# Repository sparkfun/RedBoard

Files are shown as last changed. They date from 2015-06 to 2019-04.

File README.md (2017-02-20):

SparkFun RedBoard
============================

[SparkFun RedBoard  
*SparkFun RedBoard (DEV-13975)*](https://www.sparkfun.com/products/13975)

The RedBoard combines the simplicity of the UNO's Optiboot bootloader (which is used in the Pro series), the stability of the FTDI (which we all missed after the Duemilanove was discontinued) and the R3 shield compatibility of the latest Arduino UNO R3.

The RedBoard can be programmed over a USB Mini-B cable using the Arduino IDE: Just plug in the board, select "Arduino UNO" from the board menu and you're ready to upload code.

Repository Contents
-------------------
* **/Documentation** - Data sheets, additional product information
* **/Hardware** - Eagle design files (.brd, .sch)
* **/Production** - Production panel files (.brd)

Documentation
--------------
* **[Hookup Guide](https://learn.sparkfun.com/tutorials/redboard-hookup-guide)** - Basic hookup guide for the Redboard.
* **[SparkFun Fritzing repo](https://github.com/sparkfun/Fritzing_Parts)** - Fritzing diagrams for SparkFun products.
* **[SparkFun 3D Model repo](https://github.com/sparkfun/3D_Models)** - 3D models of SparkFun products. 

License Information
-------------------

This product is _**open source**_! 

Please review the LICENSE.md file for license information. 

If you have any questions or concerns on licensing, please contact techsupport@sparkfun.com.

Distributed as-is; no warranty is given.

- Your friends at SparkFun.

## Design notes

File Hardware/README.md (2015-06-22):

SparkFun Redboard Design Files
=====================================

The .sch and .brd files hare are Eagle CAD schematic and PCB design files from SparkFun Electronics.
A freeware version of Eagle can be found [here](http://www.cadsoftusa.com/download-eagle/freeware/).

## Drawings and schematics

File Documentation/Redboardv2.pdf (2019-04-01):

# RedBoard (DEV-13975)

## Programmed with Arduino (Uno)

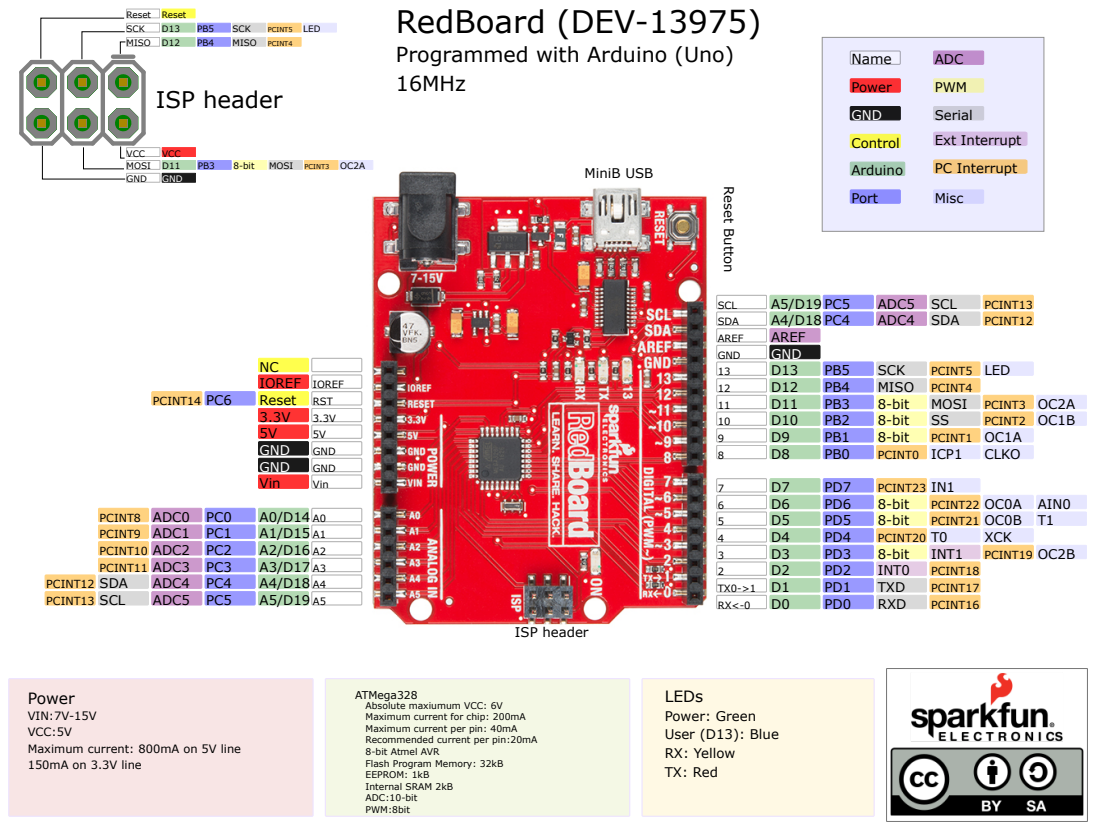
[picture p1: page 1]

ATMega328
Absolute maxiumum VCC: 6V
Maximum current for chip: 200mA
Maximum current per pin: 40mA
Recommended current per pin:20mA
8-bit Atmel AVR
Flash Program Memory: 32kB
EEPROM: 1kB
Internal SRAM 2kB
ADC:10-bit
PWM:8bit

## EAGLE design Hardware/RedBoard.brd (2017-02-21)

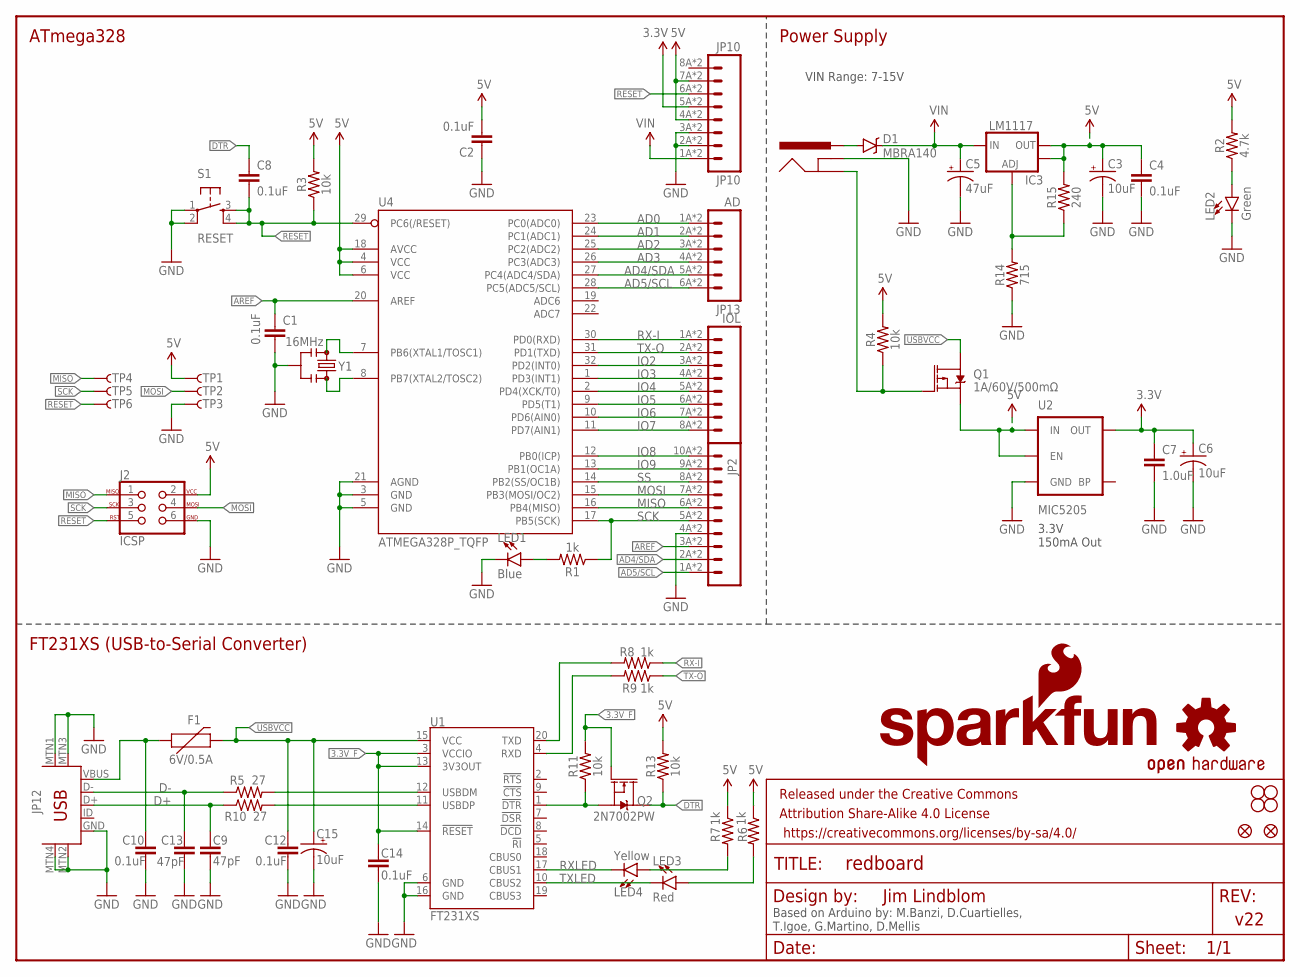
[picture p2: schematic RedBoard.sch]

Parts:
C1, C2, C4, C8, C10, C12, C14: 0.1uF; 0603
C3, C6, C15: 10uF; EIA3216
C5: 47uF; PANASONIC_D
C7: 1.0uF; 0603
C9, C13: 47pF; 0603
D1: MBRA140; SMA-DIODE
F1: 6V/0.5A; 1206
FRAME2: FRAME-LETTER; CREATIVE_COMMONS
IC3: LM1117; SOT223-ALT1
J2: ICSP; 2X3_SMT_POSTS
J3: POWER_JACKSUPER_BOMB_DIGITY; POWER_JACK_SMD_OVERPASTE_SUPER_BOMB_DIGITY
JP1: SFE_LOGO_NAME.1_INCH; SFE_LOGO_NAME_.1
JP2: M10SMD_COMBO; 1X10_SMD_COMBINED
JP3, JP4, JP5, JP6: STAND-OFF
JP7: SFE_LOGO_FLAME.1_INCH; SFE_LOGO_FLAME_.1
JP8, JP9: FIDUCIAL1X2; FIDUCIAL-1X2
JP10: JP10; 1X08_SMD_COMBINED
JP11: IOL; 1X08_SMD_COMBINED
JP12: USB-MINIB-5PIN; USB-MINIB
JP13: AD; 1X06_SMD_STRAIGHT_COMBO
LED1: Blue; LED-1206
LED2: Green; LED-1206
LED3: Red; LED-1206
LED4: Yellow; LED-1206
Q1: 1A/60V/500mΩ; SOT23-3
Q2: 2N7002PW; SOT323
R1, R6, R7, R8, R9: 1k; 0603
R2: 4.7k; 0603
R3, R4, R11, R13: 10k; 0603
R5, R10: 27; 0603
R14: 715; 0603
R15: 240; 0603
S1: RESET; TACTILE-SWITCH-SMD
TP1, TP2, TP3, TP4, TP5, TP6: TP-3x5; PAD.03X.05
U1: FT231XS; SSOP20_L
U2: MIC5205; SOT23-5
U4: ATMEGA328P_TQFP; TQFP32-08
U$16: OSHW-LOGOS; OSHW-LOGO-S
Y1: 16MHz; RESONATOR-SMD-3.2X1.3

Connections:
3.3V: C6.+, C7.1, JP10.5A (5), JP10.5B (5), U2.5 (OUT)
3.3V_F: C14.1, Q2.1 (G), R11.2, U1.3 (VCCIO), U1.13 (3V3OUT), U1.14 (!RESET)
5V: C2.2, C3.+, C4.1, IC3.2 (OUT), IC3.4 (OUT), J2.2, JP10.4A (4), JP10.4B (4), JP10.7A (7), JP10.7B (7), Q1.2 (S), R2.2, R3.2, R4.2, R6.1, R7.1, R13.2, R15.2, TP1.P$1, U2.1 (IN), U2.3 (EN), U4.4 (VCC), U4.6 (VCC), U4.18 (AVCC)
AD0: JP13.1A (1), JP13.1B (1), U4.23 (PC0(ADC0))
AD1: JP13.2A (2), JP13.2B (2), U4.24 (PC1(ADC1))
AD2: JP13.3A (3), JP13.3B (3), U4.25 (PC2(ADC2))
AD3: JP13.4A (4), JP13.4B (4), U4.26 (PC3(ADC3))
AD4/SDA: JP2.2A (2), JP2.2B (2), JP13.5A (5), JP13.5B (5), U4.27 (PC4(ADC4/SDA))
AD5/SCL: JP2.1A (1), JP2.1B (1), JP13.6A (6), JP13.6B (6), U4.28 (PC5(ADC5/SCL))
AREF: C1.1, JP2.3A (3), JP2.3B (3), U4.20 (AREF)
D+: C9.1, JP12.D+, R10.1
D-: C13.1, JP12.D-, R5.1
DTR: C8.1, Q2.3 (D), R13.1
FTDI_DTR: Q2.2 (S), R11.1, U1.1 (!DTR)
GND: C1.2, C2.1, C3.-, C4.2, C5.-, C6.-, C7.2, C9.2, C10.2, C12.2, C13.2, C14.2, C15.-, J2.6, J3.GND (GNDBREAK), JP2.4A (4), JP2.4B (4), JP10.2A (2), JP10.2B (2), JP10.3A (3), JP10.3B (3), JP12.GND, JP12.MTN1 (MTN2), JP12.MTN2 (MTN3), JP12.MTN3 (MTN1), JP12.MTN4, LED1.C, LED2.C, R14.1, S1.1, S1.2, TP3.P$1, U1.6 (GND), U1.16 (GND), U2.2 (GND), U4.3 (GND), U4.5 (GND), U4.21 (AGND), Y1.2
INSERT: J3.P$4 (GND), Q1.1 (G), R4.1
IO2: JP11.3A (3), JP11.3B (3), U4.32 (PD2(INT0))
IO3: JP11.4A (4), JP11.4B (4), U4.1 (PD3(INT1))
IO4: JP11.5A (5), JP11.5B (5), U4.2 (PD4(XCK/T0))
IO5: JP11.6A (6), JP11.6B (6), U4.9 (PD5(T1))
IO6: JP11.7A (7), JP11.7B (7), U4.10 (PD6(AIN0))
IO7: JP11.8A (8), JP11.8B (8), U4.11 (PD7(AIN1))
IO8: JP2.10A (10), JP2.10B (10), U4.12 (PB0(ICP))
IO9: JP2.9A (9), JP2.9B (9), U4.13 (PB1(OC1A))
MISO: J2.1, JP2.6A (6), JP2.6B (6), TP4.P$1, U4.16 (PB4(MISO))
MOSI: J2.4, JP2.7A (7), JP2.7B (7), TP2.P$1, U4.15 (PB3(MOSI/OC2))
unnamed: LED1.A, R1.2
unnamed: LED2.A, R2.1
unnamed: U4.7 (PB6(XTAL1/TOSC1)), Y1.1
unnamed: U4.8 (PB7(XTAL2/TOSC2)), Y1.3
unnamed: R5.2, U1.12 (USBDM)
unnamed: R10.2, U1.11 (USBDP)
unnamed: LED3.A, R6.2
unnamed: LED4.A, R7.2
unnamed: IC3.1 (ADJ), R14.2, R15.1
PWRIN: D1.A, J3.VIN0 (PWR)
RESET: C8.2, J2.5, JP10.6A (6), JP10.6B (6), R3.1, S1.3, S1.4, TP6.P$1, U4.29 (PC6(/RESET))
RX-I: JP11.1A (1), JP11.1B (1), R8.1, U4.30 (PD0(RXD))
RXD: R9.2, U1.4 (RXD)
RXLED: LED4.C, U1.17 (CBUS1)
SCK: J2.3, JP2.5A (5), JP2.5B (5), R1.1, TP5.P$1, U4.17 (PB5(SCK))
SS: JP2.8A (8), JP2.8B (8), U4.14 (PB2(SS/OC1B))
TX-O: JP11.2A (2), JP11.2B (2), R9.1, U4.31 (PD1(TXD))
TXD: R8.2, U1.20 (TXD)
TXLED: LED3.C, U1.10 (CBUS2)
USBVCC: C12.1, C15.+, F1.2, Q1.3 (D), U1.15 (VCC)
VIN: C5.+, D1.C, IC3.3 (IN), JP10.1A (1), JP10.1B (1)
VUSB: C10.1, F1.1, JP12.VBUS

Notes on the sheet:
Power Supply
ATmega328
FT231XS (USB-to-Serial Converter)
Based on Arduino by: M.Banzi, D.Cuartielles, T.Igoe, G.Martino, D.Mellis
3.3V 150mA Out
Jim Lindblom
v22
VIN Range: 7-15V

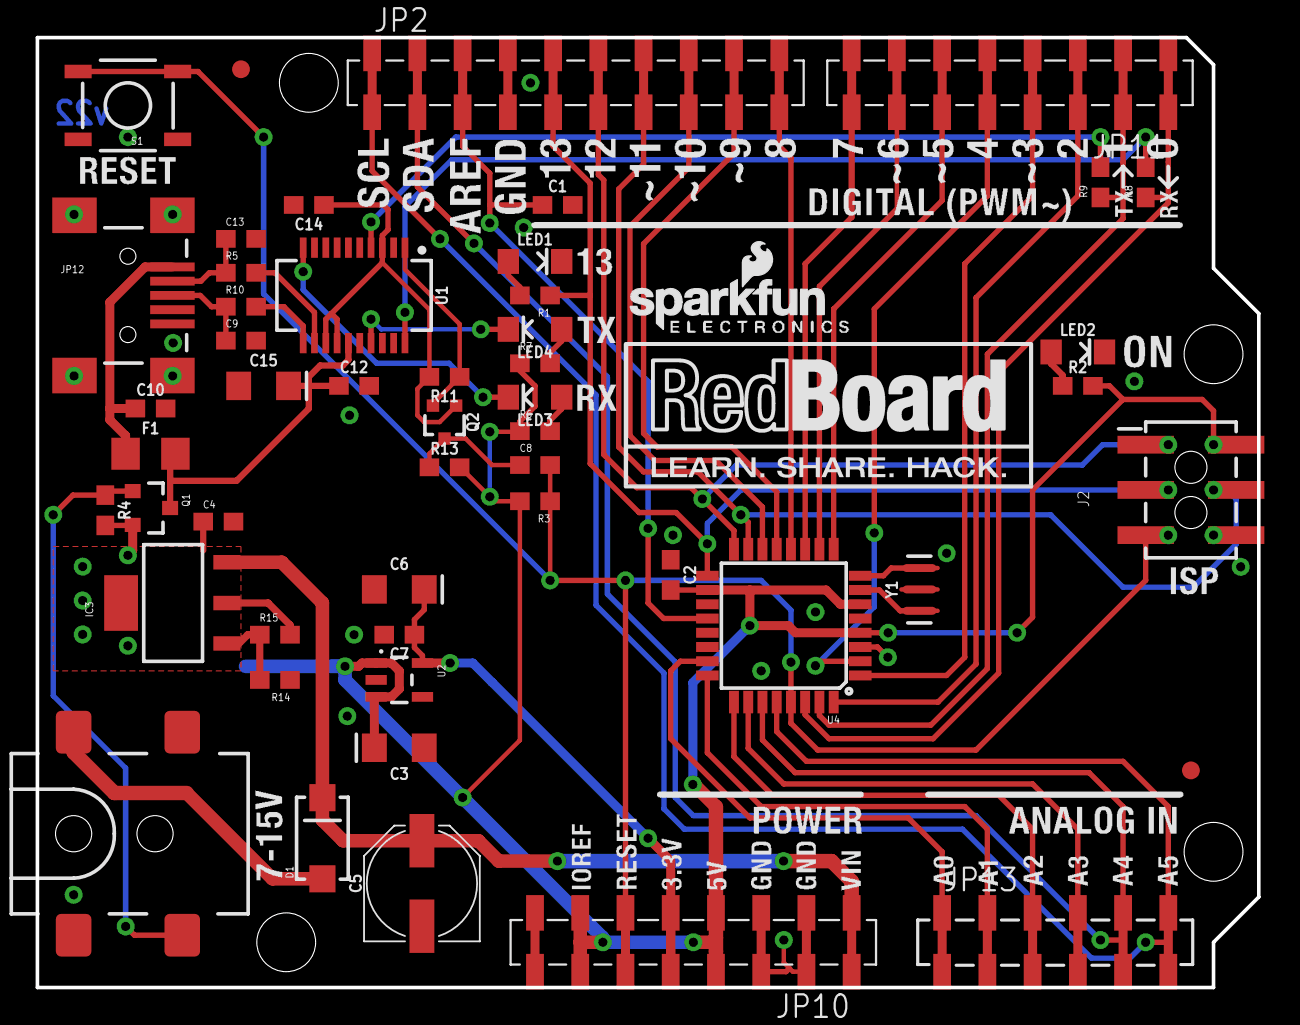
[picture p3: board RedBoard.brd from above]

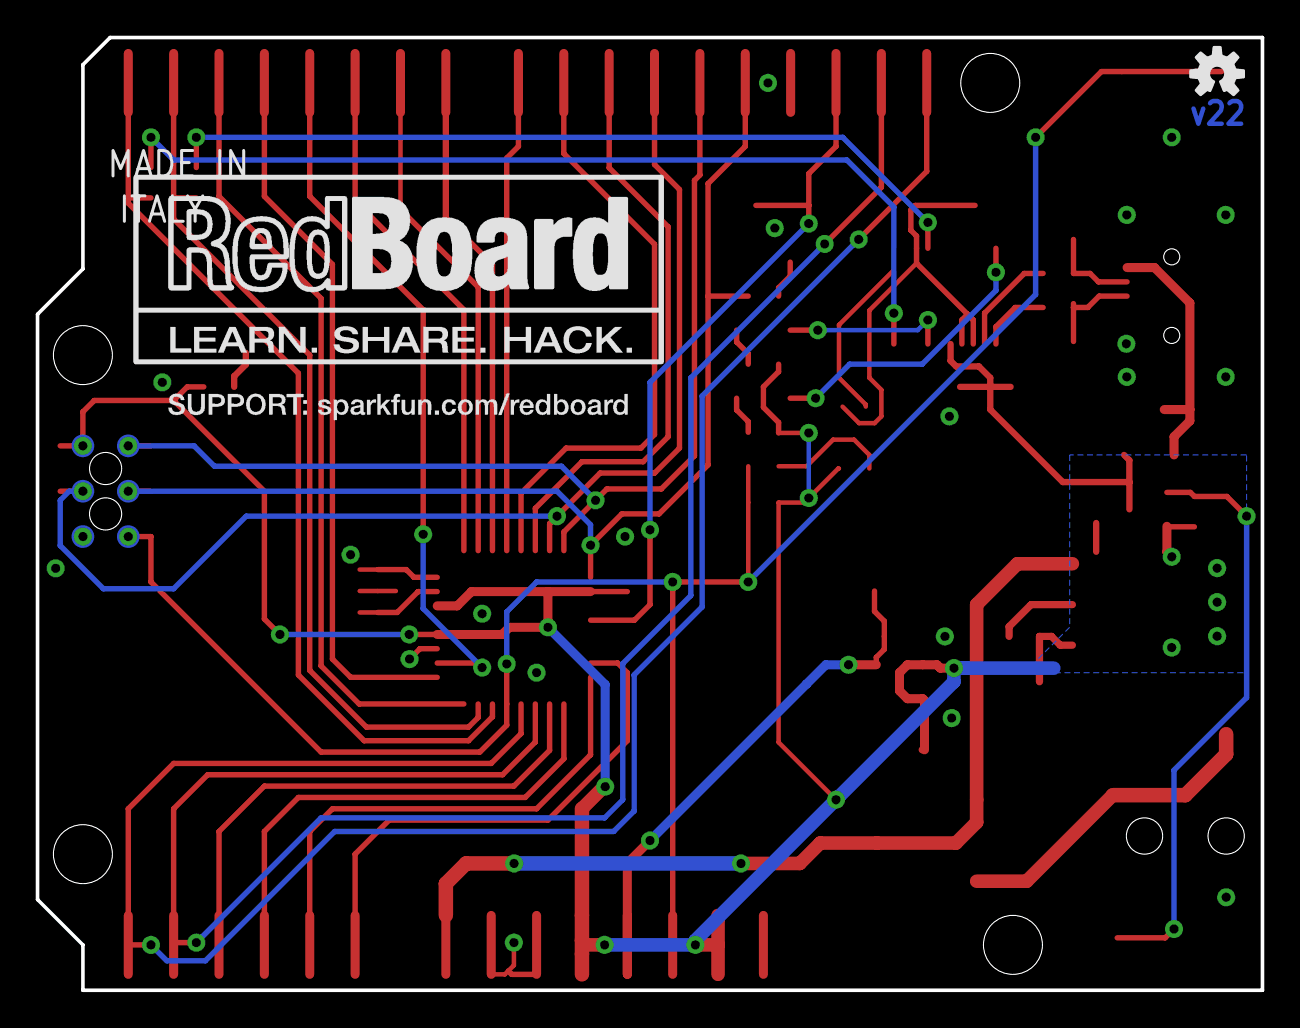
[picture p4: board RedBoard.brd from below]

Board: 2 copper layers, 68.6 x 53.3 mm, 65 parts (7 on the bottom side), 48 nets.

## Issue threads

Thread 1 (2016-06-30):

Checklist design review for v22

lewispg228, 2016-06-30:
1) We need to reconsider the resistor values on the LEDs. They are _very_ bright. This has been a common complaint from EDU, and there are lots of comments on the product page about this being an issue.

2) Depending on what the DFM agrees to this Friday, I'm suggesting that we revert the silk to the previous style for the 10uF caps (C3, C6 and C13). I think the line for the positive side of a polarized cap will be confusing.

*I'll wait to finish BOM verification until we decide what to do here.

3) The mark on the STAT LED (13) is not ideal. I suggest we possibly revert these packages as well for this rev. Or we flip the LED 180 degrees.

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

4) should probably get the "v22 revised by: jim" in the sch and brd too. Also, the board is missing the other "based on:...." text objects.

5) Do we want to put a line over RESET pin silk? (it isn't really standard for us, but it is an active low pin, right?)

mgrusin, 2016-06-30:
We in Edu have noticed odd behavior when running higher-current loads such as motors through the board to VIN; things like the board browning out etc. We support reviewing and upgrading the power paths to make sure they're extra-wide, smooth, and well-isolated.

jimblom, 2016-07-06:
@lewispg228 1. 4.7k on the power LED seems to cut the green LED's intensity down to a level similar to the blue pin 13 LED. That's the only one that seems really egregious to me.
2. Whatever's best for production. We can talk about it Friday.
3. Agreed. Reverted back to old silkscreen to avoid changing copper.
4. I added the "Based on..." text to the board. If I'm the original designer, is a "revised by me" necessary? Eh.
5. Noticed that too, but I'm trying to avoid dramatically changing any silk. There's precedent for the bar-less RESET label on other Arduino boards, I think it's safe to leave off this one.

Changes pushed.

ToniCorinne, 2017-02-08:
This rev is almost ready to go live. Closing out the issue as resolved.

Closed 2017-02-08.

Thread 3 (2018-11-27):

RedBoard Qwiic Double Check

JoshuaSparkfun, 2018-11-27:
*1) This is all still in a branch from the main Redboard. Any independent repo in github for the product might be appropriate.

1) Have you verified that the BOM in Sparkle is accurate (also checking for PROD_ID, NAME, VALUE, PREFIX)? [NO]
comment: There is no current Redboard Qwiic in sparkle. The BOM does not match up with the current Blackboard in sparkle.

2) Are 0.1 inch headers lined up on 0.1 inch grid? [NO]
comment: The SCL,SDA, AREF GND 9-13 pins Header is not aligned on a .1 inch grid and is not aligned with the other headers

3) Is the LED color standard followed? (red for power, blue for STAT, green for TX, yellow for RX) [NO]
comment: The "ON" / Power LED is Green which is consistent with the Redboards but not our other products.

4) Are there fiducials on both the TOP and BOTTOM of the board? [NO]
comment: Fiducials were only found on  top layer

5) Is the CC/Design By included in tDocu? [NO]
comment: Needs Designer and revisor names

6) Is 'Revised by:' and 'Revisor Name' included in tDocu? [NO]
comment: Needs Names

7) Do all components have polarity or pin 1 labeled? [NO]
comment: IC-14038 Needs Polarity labeled on silk

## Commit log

2014-01-27 v06 Hardware - Currently live files
    [RedBoard.brd, RedBoard.sch]
2014-02-03 New SMD ICSP header, logo, FT231X, power select
    [RedBoard.brd, RedBoard.sch]
2014-02-05 Switch RX/TX labels, updating back logo
    [RedBoard.brd, RedBoard.sch]
2014-02-05 LEDs to 1206; new barrel jack fp; moved 5V vreg
    [RedBoard.brd, RedBoard.sch]
2014-02-05 Spacing out caps and resistors
    [RedBoard.brd]
2014-03-03 Moved C1 cap around silk. Moved some top silk.
    [RedBoard.brd, RedBoard.sch]
2014-03-03 Moving vias off programming test points
    [RedBoard.brd]
2014-03-04 Tailing in ISP header pins
    [RedBoard.brd, RedBoard.sch]
2014-03-04 Back to old ISP. Tucked in the paste on edge pins
    [RedBoard.brd, RedBoard.sch]
2014-08-07 Adjustments to FT231X circuit. Package updates.
    - Disconnecting FTDI 3.3V (VCCIO) from ATmega328's 3.3V bus
    - Getting rid of MOSFET on DTR line. 5V, 10k pull-up does the job just
    fine.
    - Adding vias to ISP test points.
    - Tailing the dimensions of the board in a bit. Board is now
    Arduino-standard 2.1" tall (was 2.14")
    - Updating 1x10, 1x08, and 1x06 packages to minimize false DRC errors.
    - Updating these packages for QC: resonator, MBRA140 diode, PTC, barrel
    jack, reset button.
    [RedBoard.brd, RedBoard.sch]
2014-08-11 upping version number to v22`
    [RedBoard.brd, RedBoard.sch]
2014-08-13 reverting back to old DTR circuit
    [RedBoard.brd, RedBoard.sch]
2015-06-22 Adding svg/pdf of Redboard, adding license and .git files, updating readme
    [SparkFunRedBoard.brd, SparkFunRedBoard.sch]
2015-12-09 moved panel fiducials. board unchanged
2016-06-27 Schematic cleanup and minor updates post-checklist.
    [RedBoard.brd, RedBoard.sch]
2016-06-27 Updating libraries where they don't affect copper.
    [RedBoard.brd, RedBoard.sch]
2016-06-27 Updating 2x3 connector to show pin position.
    [RedBoard.brd, RedBoard.sch]
2016-07-06 Fixing LED silk, changing power LED resistor.
    [RedBoard.brd, RedBoard.sch]
2016-07-19 Fixing PROD_ID on J2 and C10.
    [RedBoard.brd, RedBoard.sch]
2017-02-21 Component Values Updated for 3D Model
    [RedBoard.brd, RedBoard.sch]
2019-04-01 Update Graphical Datasheet
    -Correct Port Name on Pin 10
    -update image
    -update SKU
    -Rename files based on the correction from Graphical Datasheet Repo

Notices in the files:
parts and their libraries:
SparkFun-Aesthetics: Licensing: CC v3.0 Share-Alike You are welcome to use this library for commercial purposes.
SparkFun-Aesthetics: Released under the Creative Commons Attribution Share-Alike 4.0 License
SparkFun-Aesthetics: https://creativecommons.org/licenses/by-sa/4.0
